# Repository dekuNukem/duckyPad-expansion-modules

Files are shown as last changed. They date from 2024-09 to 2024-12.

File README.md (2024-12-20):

# duckyPad Expansion Module

[Pre-order](https://www.kickstarter.com/projects/dekunukem/duckypad-pro-advanced-macro-scripting-beyond-qmk-via) | [Official Discord](https://discord.gg/4sJCBx5) | [Project Page](https://github.com/dekuNukem/duckyPad-Pro) | [Table of Contents](#table-of-contents)

duckyPad Expansion Module lets you wire up external **switches / buttons / foot pedals** to your duckyPad Pro.

* **8 Channels** Per Module

* **Daisy-Chain** up to 32 Channels

* USB-C Connector

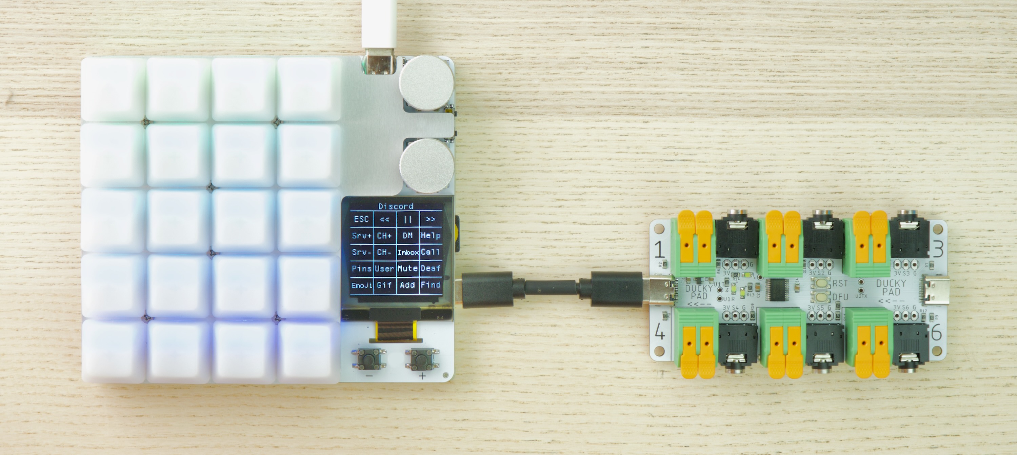
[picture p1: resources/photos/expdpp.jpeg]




## Table of Contents

- [Kit Assembly](#kit-assembly)
- [Connection Overview](#connection-overview)
	- [Terminal Block](#connection-terminal-block)
	- [3.5mm Audio Jack](#connection-35mm-audio-jack)
	- [Pin Headers](#connection-pin-headers)
- [Key Test](#key-test)
- [Configurator](#configurator)

## Kit Assembly

* **Wash your hands first** to discharge static electricity

You should have the following parts:

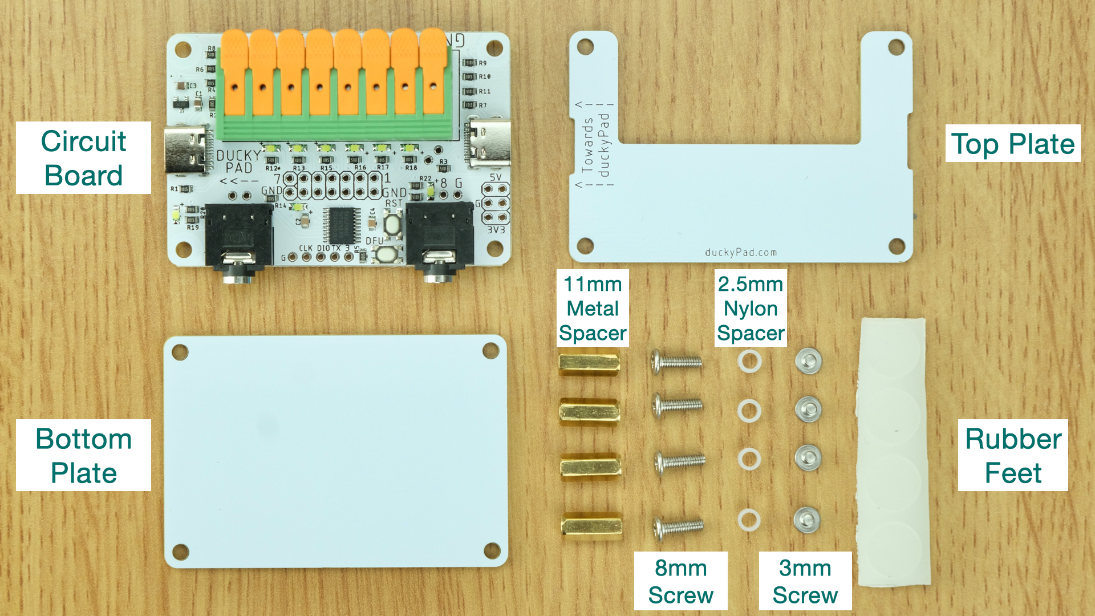
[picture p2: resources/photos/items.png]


Insert the `8mm Screws` in `Bottom Plate`:

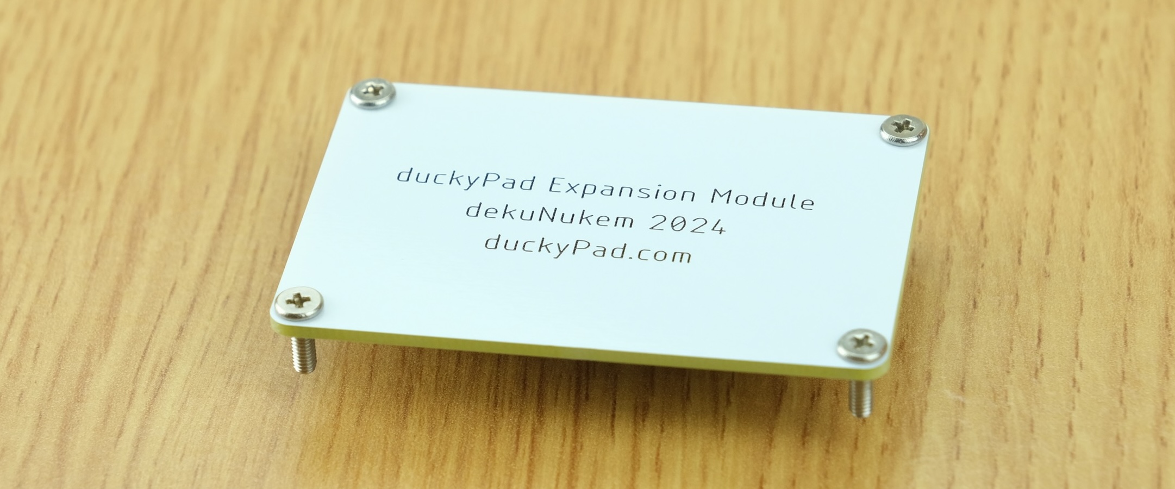
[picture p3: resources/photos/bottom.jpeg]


Place **something rigid** against the back, and flip over.

The screws should stay in place.

Put on **2.5mm Nylon Spacers**.

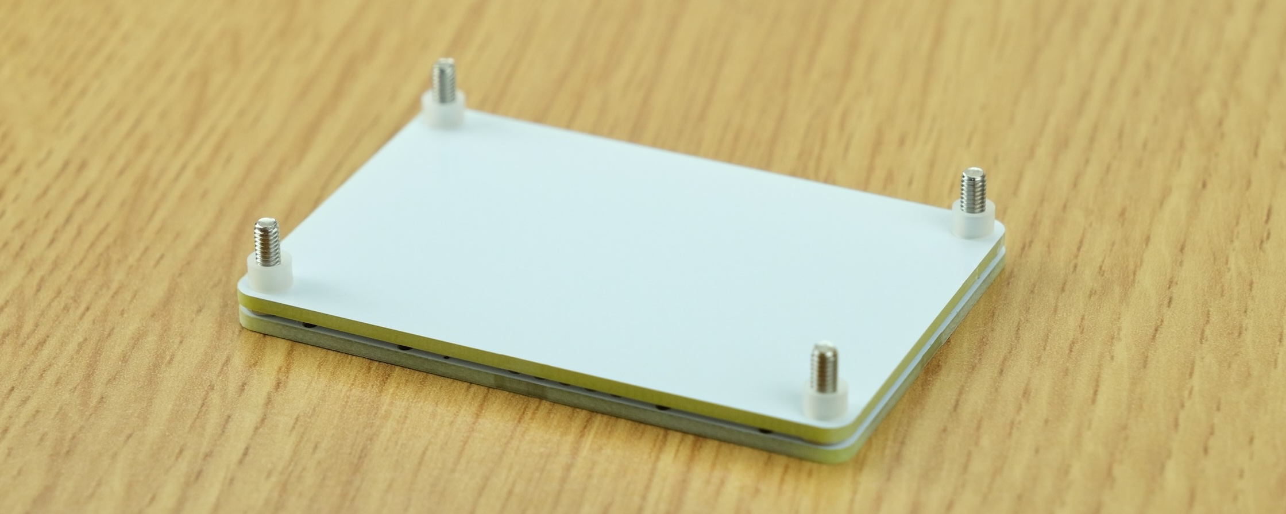
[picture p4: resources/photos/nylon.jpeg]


Insert the `Circuit Board`.

Then the `8mm Metal Spacer`

* **Moderately tighten** with a socket bit if available

* Avoid scratching the PCB or nearby components.

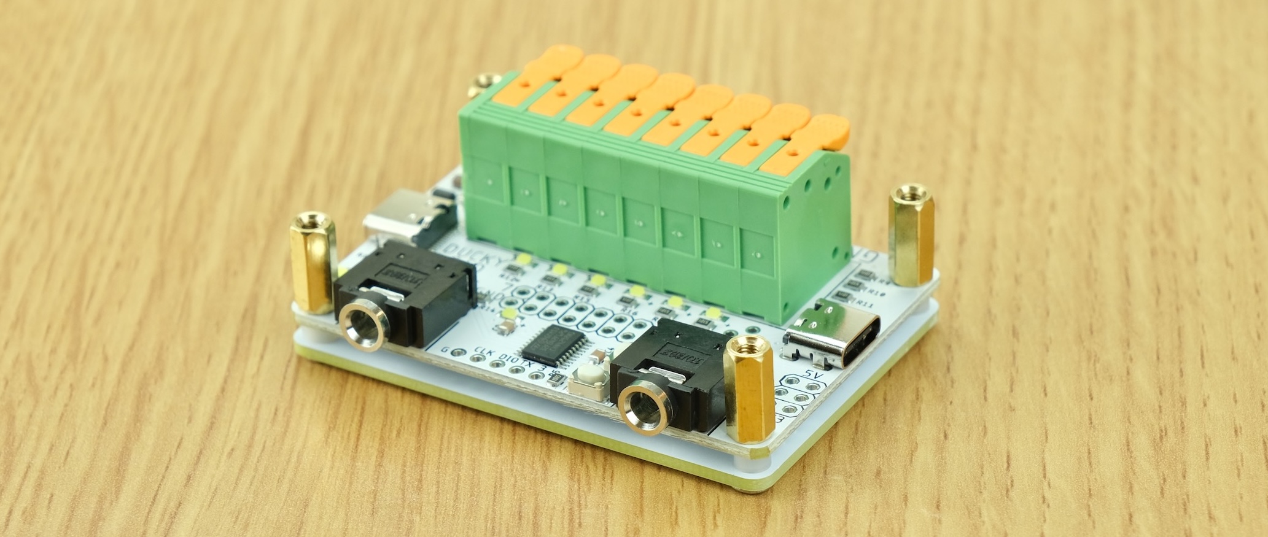
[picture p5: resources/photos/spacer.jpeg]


Leave the `Top Plate` off for now.

You can install it after everything is wired up.

## Back to duckyPad!

If you're just starting, **set up your duckyPad first by [following the User Guide](https://dekunukem.github.io/duckyPad-Pro/doc/getting_started.html)**

Play with scripts on built-in switches and encoders, continue here once familiarised.

## Connection Overview

**8 Channels** are available per module.

* Numbered 1 to 8
* A channel is **considered active** when it is **shorted to ground (GND)**.

Therefore, to wire up a switch, you just need to:

* Connect **one side** to **GND**
* And the **other side** to the **desired channel**

---------

You can make connections via:

* Terminal Block
* 3.5mm Jack
* Pin Headers

## Connection: Terminal Block

Take a look at the `terminal block`:

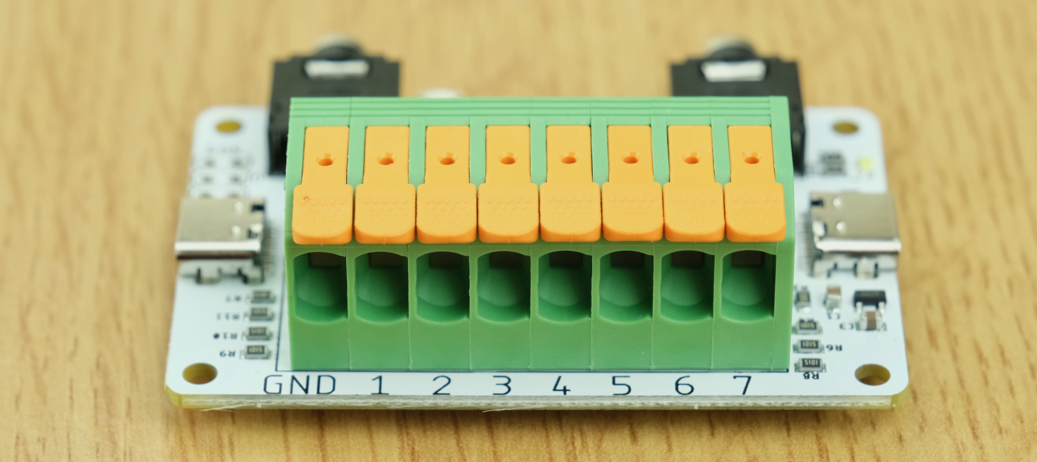
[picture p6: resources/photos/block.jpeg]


Contains **Channel 1 to 7** and **GND**

To wire up a switch, connect it between a channel and GND.

-------

As an example, here's a simple button with two wires:

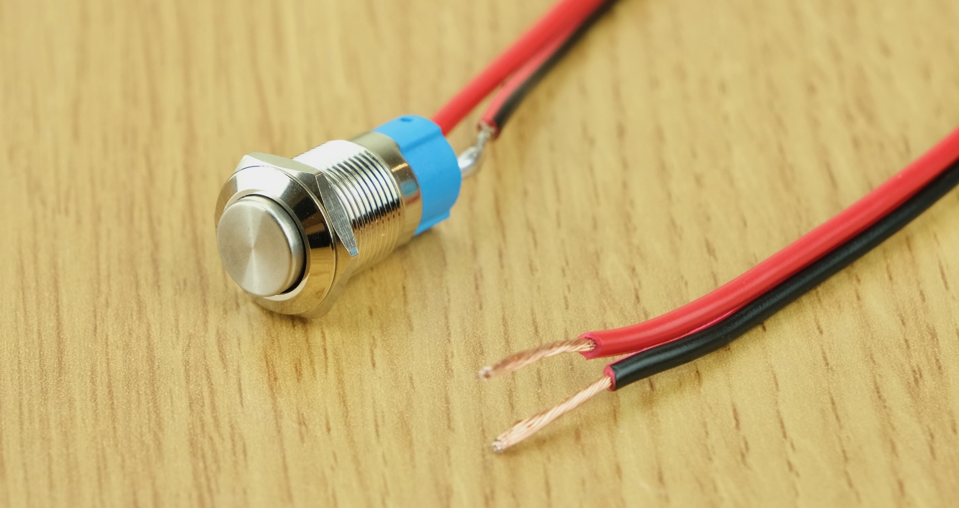
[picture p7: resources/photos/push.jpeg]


* When not pushed, the wires are isolated.
* When pushed, they are **connected together**.

Therefore, we just need to attach one wire to GND, and the other to a channel.

* Flip up the lever for GND and the desired channel

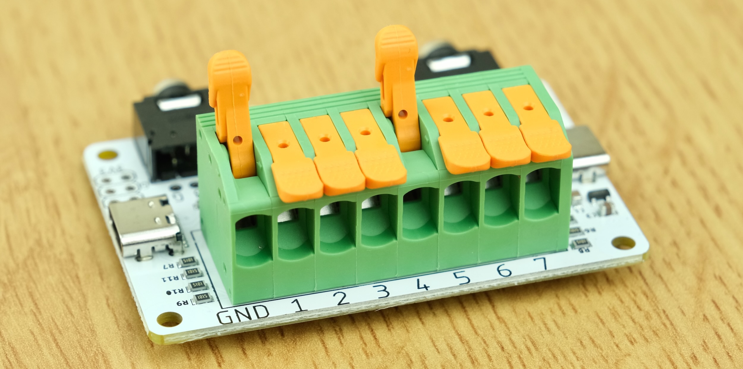
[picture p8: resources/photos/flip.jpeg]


* Strip around half inch / 1.2cm of conductor
* Insert into the hole
* Flip lever back down

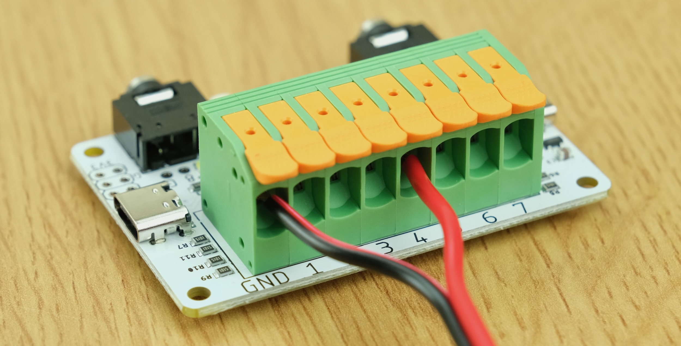
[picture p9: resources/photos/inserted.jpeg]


## Connection: 3.5mm Audio Jack

Two 3.5mm TRS (Tip, Ring, Sleeve) connectors are available.

Sleeve is connected to GND.

Tip and Ring are connected to channels shown below.

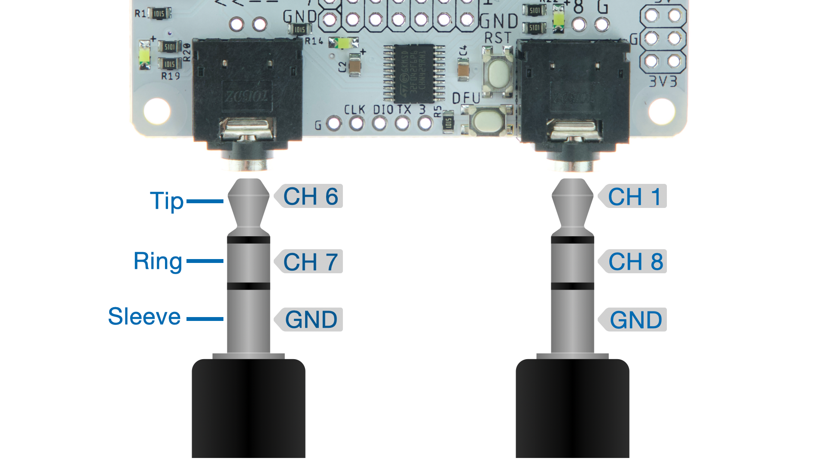
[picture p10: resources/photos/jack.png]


## Connection: Pin Headers

All channels are also available on pin headers.

You can install a header or solder wires directly to them.

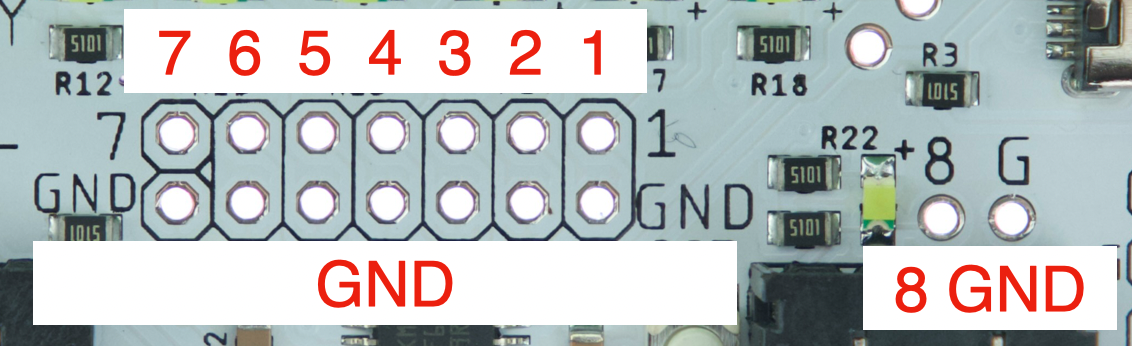
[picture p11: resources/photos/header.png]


## Key Test

Use a USB-C cable and connect the module as shown.

* Make sure the `Towards duckyPad` marking faces duckyPad

* The other end is used for daisy-chaining

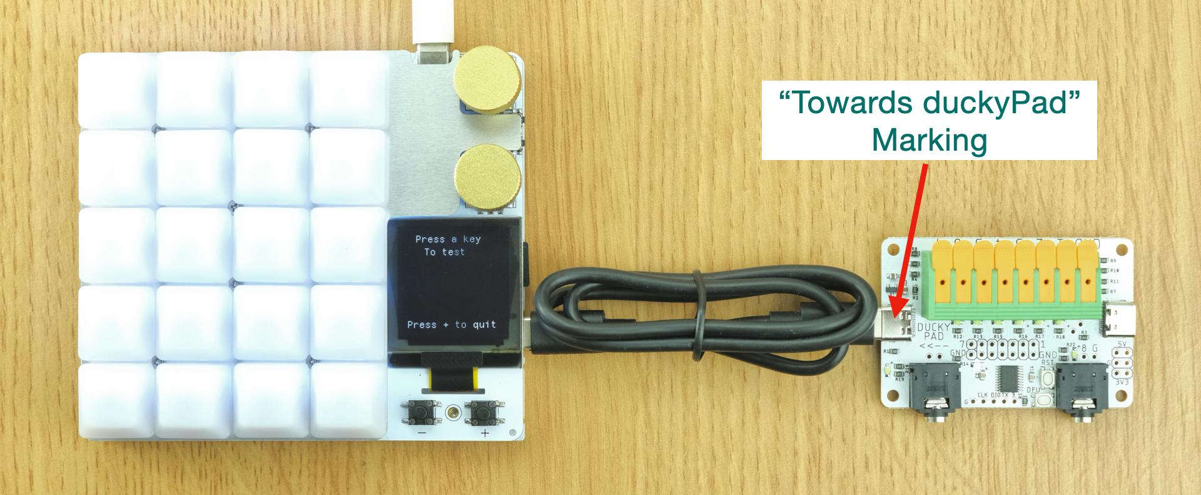
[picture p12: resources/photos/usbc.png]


Press the `Key Test` script in `Welcome` profile

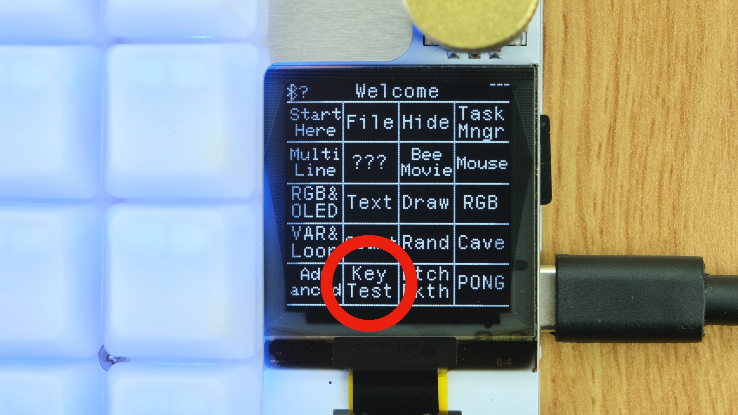
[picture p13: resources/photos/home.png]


Press a built-in switch, the screen should respond.

Then activate a channel on the expansion module.

The corresponding LED should light up:

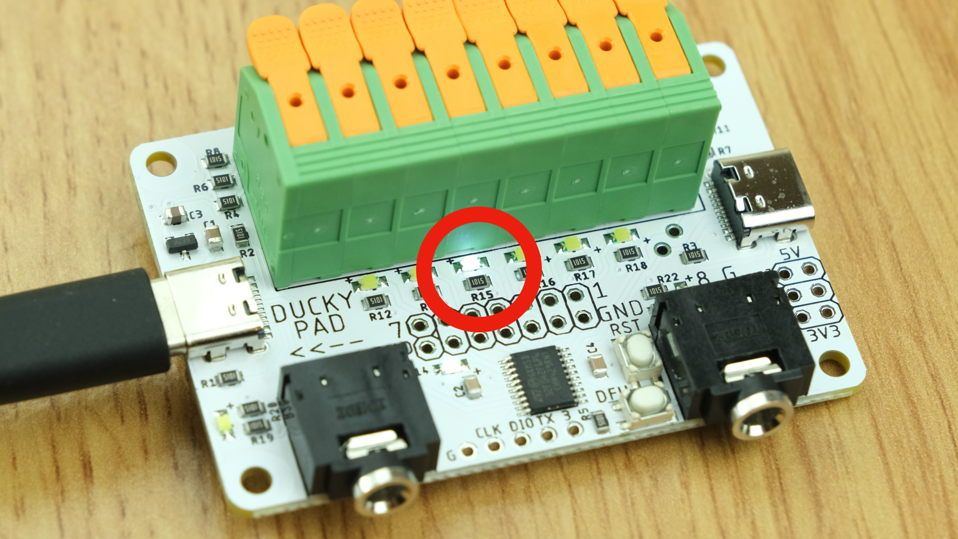
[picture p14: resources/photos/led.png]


The screen should show too:

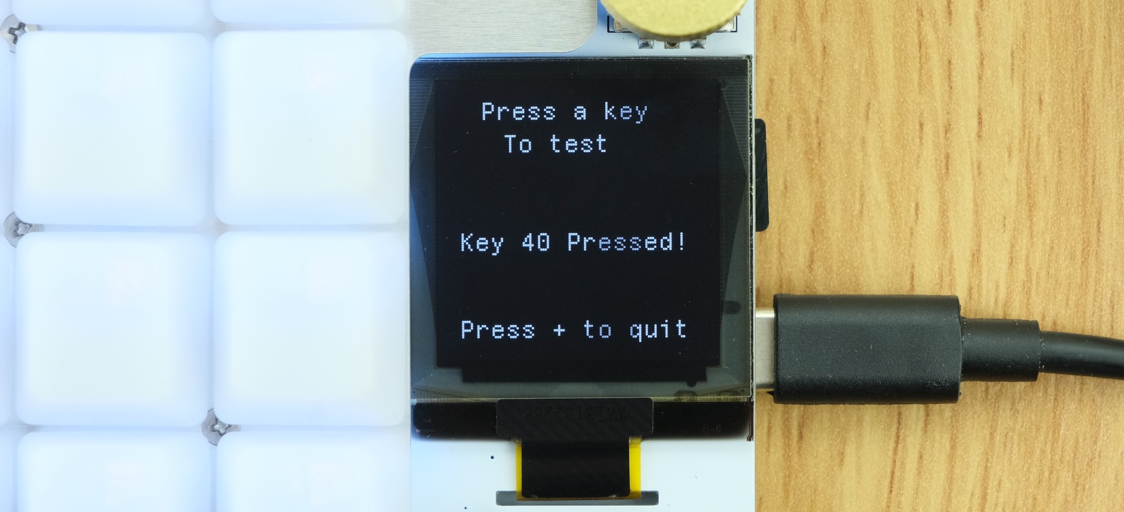
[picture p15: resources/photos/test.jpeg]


If so, congrats! Your wiring is correct.

## Configurator

You can assign actions to expansion channels just like any other key.

Module 1 is closest to duckyPad, up to 4 can be daisy-chained.

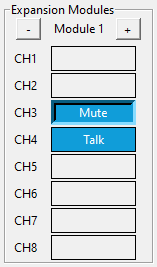
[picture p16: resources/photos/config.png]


Some notes:

* If using a flip switch, select `Disable Auto-Repeat`.
* So the script doesn't repeat after changing state.

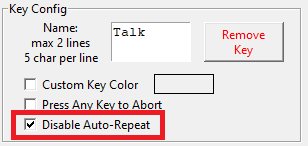
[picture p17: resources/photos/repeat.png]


* Each channel can have different scripts for `onPress` and `onRelease`.
	* `onPress` is when a channel goes from inactive to active
	* `onRelase` is the opposite



## Questions or Comments?

Please feel free to [open an issue](https://github.com/dekuNukem/duckypad-pro/issues), ask in the [official duckyPad discord](https://discord.gg/4sJCBx5), or email `dekuNukem`@`gmail`.`com`!

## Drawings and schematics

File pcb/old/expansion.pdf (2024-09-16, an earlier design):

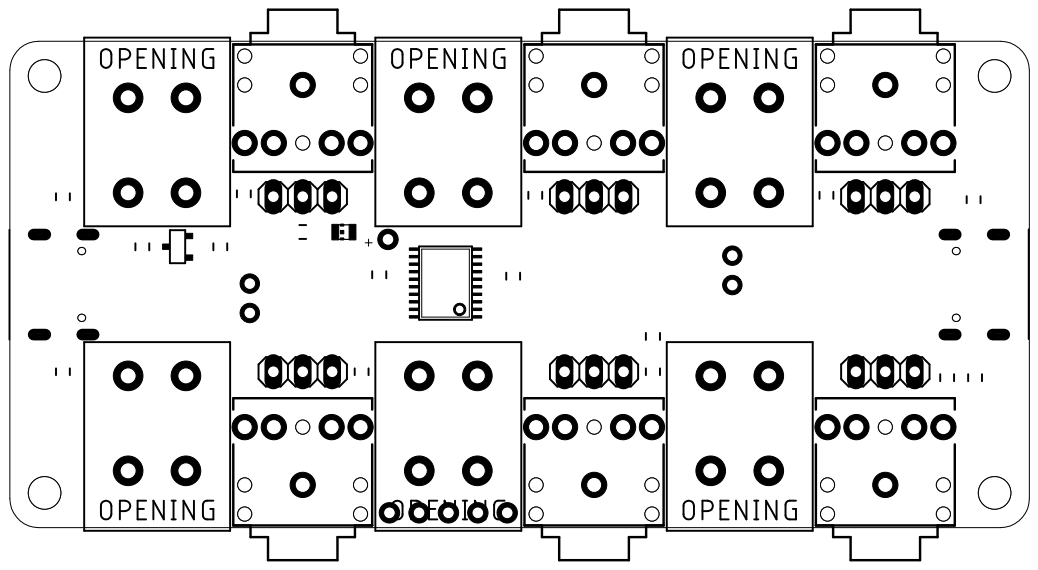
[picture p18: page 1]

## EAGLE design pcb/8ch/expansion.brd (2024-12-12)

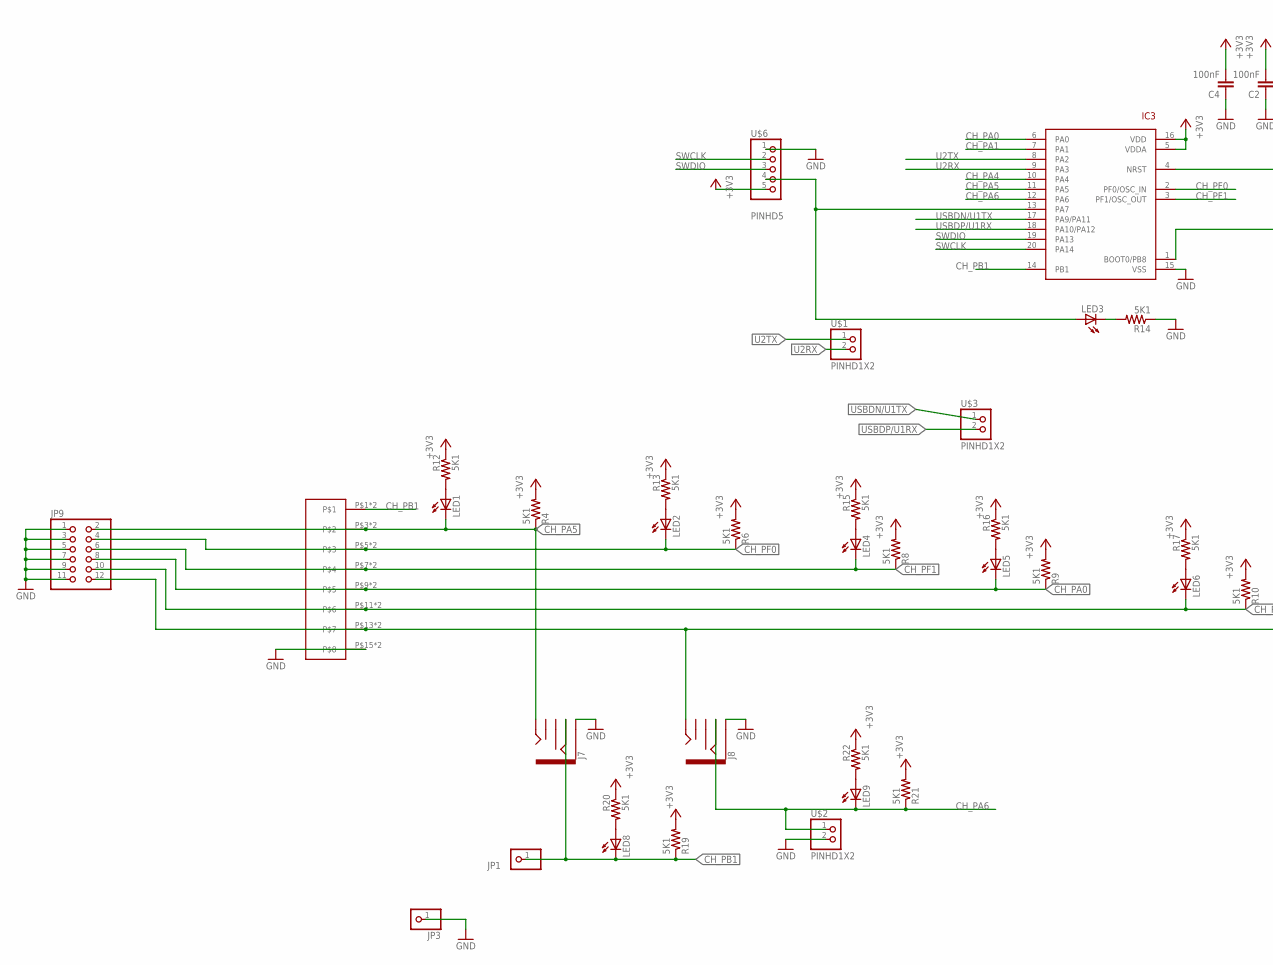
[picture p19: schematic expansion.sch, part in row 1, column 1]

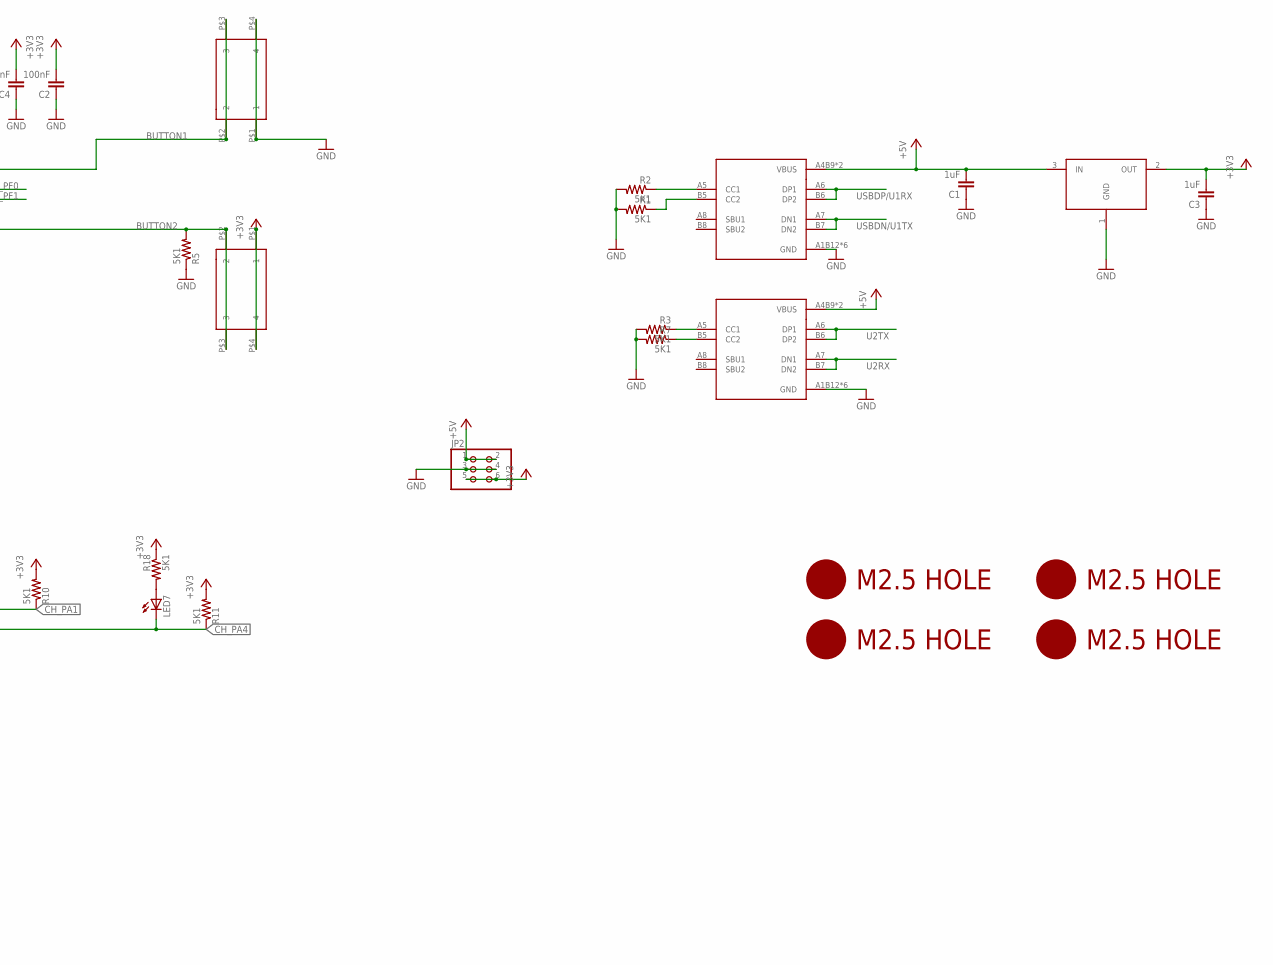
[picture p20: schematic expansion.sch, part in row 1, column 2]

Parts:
C1, C3: 1uF; 0805
C2, C4: 100nF; 0805
IC3: STM32F042F4; TSSOP20
J7, J8: AUDIO_JACK_3.5MM_PTH; AUDIO-JACK
JP1, JP3: PINHD-1X1; 1X01
JP2: PINHD-2X3; 2X03
JP9: PINHD-2X6; 2X06
LED1, LED2, LED3, LED4, LED5, LED6, LED7, LED8, LED9: LEDCHIP-LED0805; CHIP-LED0805
R1, R2, R3, R4, R5, R6, R7, R8, R9, R10, R11, R12, R13, R14, R15, R16, R17, R18, R19, R20, R21, R22: 5K1; 0805
SW3, SW4: 324_SW; 342_SWICH_FOOT
U1, U2: USBC_16P; USBC_16P_FOOT
U4: XC6206_DEV; SOT23R_INFINEON
U$1, U$2, U$3: PINHD1X2; 1X02
U$6: PINHD5; 1X05
U$8, U$9, U$10, U$11: M2.5HOLE
U$14: DG2204R-5.0-8DG2204-8; DG2204R-8

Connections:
+3V3: C2.2, C3.2, C4.2, IC3.5 (VDDA), IC3.16 (VDD), JP2.5, JP2.6, R4.2, R6.2, R8.2, R9.2, R10.2, R11.2, R12.1, R13.1, R15.1, R16.1, R17.1, R18.1, R19.2, R20.1, R21.2, R22.1, SW4.P$1 (1), SW4.P$4 (4), U4.2 (OUT), U$6.5
+5V: C1.2, JP2.1, JP2.2, U1.A4B9 (VBUS), U1.B4A9 (VBUS), U2.A4B9 (VBUS), U2.B4A9 (VBUS), U4.3 (IN)
BUTTON1: IC3.4 (NRST), SW3.P$2 (2), SW3.P$3 (3)
BUTTON2: IC3.1 (BOOT0/PB8), R5.2, SW4.P$2 (2), SW4.P$3 (3)
CH_PA0: IC3.6 (PA0), JP9.8, LED5.C, R9.1, U$14.P$9, U$14.P$10
CH_PA1: IC3.7 (PA1), JP9.10, LED6.C, R10.1, U$14.P$11, U$14.P$12
CH_PA4: IC3.10 (PA4), J8.TIP, JP9.12, LED7.C, R11.1, U$14.P$13, U$14.P$14
CH_PA5: IC3.11 (PA5), J7.TIP, JP9.2, LED1.C, R4.1, U$14.P$3, U$14.P$4
CH_PA6: IC3.12 (PA6), J8.RING, LED9.C, R21.1, U$2.1
CH_PB1: IC3.14 (PB1), J7.RING, JP1.1, LED8.C, R19.1, U$14.P$1, U$14.P$2
CH_PF0: IC3.2 (PF0/OSC_IN), JP9.4, LED2.C, R6.1, U$14.P$5, U$14.P$6
CH_PF1: IC3.3 (PF1/OSC_OUT), JP9.6, LED4.C, R8.1, U$14.P$7, U$14.P$8
GND: C1.1, C2.1, C3.1, C4.1, IC3.15 (VSS), J7.SLEEVE, J8.SLEEVE, JP2.3, JP2.4, JP3.1, JP9.1, JP9.3, JP9.5, JP9.7, JP9.9, JP9.11, R1.2, R2.2, R3.2, R5.1, R7.2, R14.1, SW3.P$1 (1), SW3.P$4 (4), U1.A1B12 (GND), U1.B11A12 (GND), U1.P$13 (GND), U1.P$14 (GND), U1.P$15 (GND), U1.P$16 (GND), U2.A1B12 (GND), U2.B11A12 (GND), U2.P$13 (GND), U2.P$14 (GND), U2.P$15 (GND), U2.P$16 (GND), U4.1 (GND), U$2.2, U$6.1, U$14.P$15, U$14.P$16
unnamed: R3.1, U1.A5 (CC1)
unnamed: R7.1, U1.B5 (CC2)
unnamed: LED1.A, R12.2
unnamed: LED2.A, R13.2
unnamed: LED4.A, R15.2
unnamed: LED5.A, R16.2
unnamed: LED6.A, R17.2
unnamed: LED7.A, R18.2
unnamed: LED8.A, R20.2
unnamed: IC3.13 (PA7), LED3.A, U$6.4
unnamed: LED3.C, R14.2
unnamed: LED9.A, R22.2
unnamed: R1.1, U2.B5 (CC2)
unnamed: R2.1, U2.A5 (CC1)
SWCLK: IC3.20 (PA14), U$6.2
SWDIO: IC3.19 (PA13), U$6.3
U2RX: IC3.9 (PA3), U1.A7 (DN1), U1.B7 (DN2), U$1.2
U2TX: IC3.8 (PA2), U1.A6 (DP1), U1.B6 (DP2), U$1.1
USBDN/U1TX: IC3.17 (PA9/PA11), U2.A7 (DN1), U2.B7 (DN2), U$3.1
USBDP/U1RX: IC3.18 (PA10/PA12), U2.A6 (DP1), U2.B6 (DP2), U$3.2

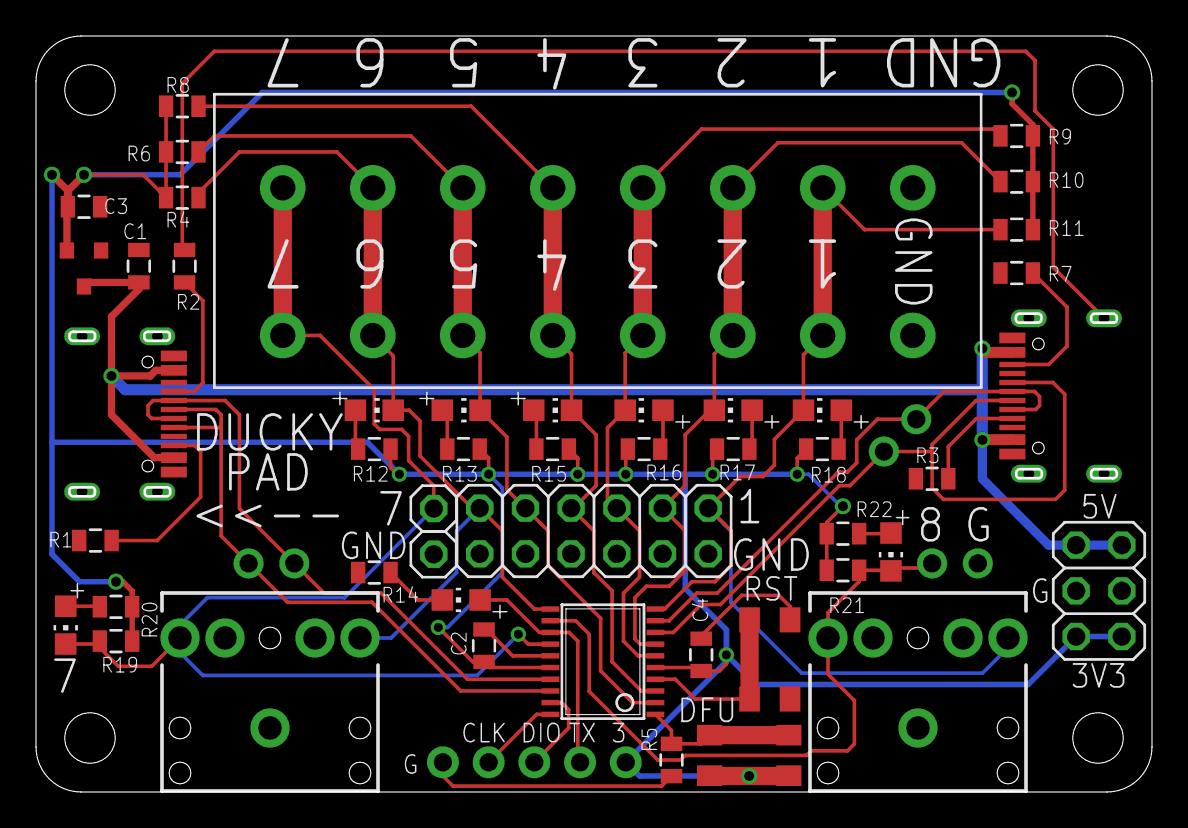
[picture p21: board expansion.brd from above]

Board: 2 copper layers, 62.0 x 42.0 mm, 56 parts (0 on the bottom side), 33 nets.

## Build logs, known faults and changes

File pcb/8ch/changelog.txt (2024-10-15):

2024 10 15

Added LED on PB1 channel

moved TX pin from PA6 to PA7

PA6 now is an additional channel

PA6 on sleeve

added LEDs on PA6

hooked up LED to TX pin, dual purpose.

Ch	Pin
1	PA4
2	PA1
3	PA0
4	PF1
5	PF0
6	PA5
7	PB1
8	PA6

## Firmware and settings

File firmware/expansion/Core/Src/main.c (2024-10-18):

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
/* Includes ------------------------------------------------------------------*/
#include "main.h"

/* USER CODE BEGIN Includes */
#include <stdio.h>
#include <string.h>
#include <stdlib.h>
#include <time.h>
#include "buttons.h"
#include "cQueue.h"
#include "softserial.h"
#include "delay_us.h"

/* USER CODE END Includes */

/* USER CODE BEGIN PTD */
int stdin_getchar (void)
{
  return 0;
}

int stdout_putchar (int ch) {
  return 0;
}
void ttywrch (int ch) {
  return;
}
/* USER CODE END PTD */

/* USER CODE BEGIN PD */

/*
2024 08 12
0.0.1
first commit

2024 10 15
0.1.0
8 channels
LED double blinks with button press and upstream receive
*/
uint8_t fw_version_major = 0;
uint8_t fw_version_minor = 1;
uint8_t fw_version_patch = 0;

#define UART_BUF_SIZE 16

uint8_t towards_duckypad_tx_buf[UART_BUF_SIZE];
uint8_t towards_duckypad_rx_buf[UART_BUF_SIZE];
uint8_t away_from_duckypad_tx_buf[UART_BUF_SIZE];
uint8_t away_from_duckypad_rx_buf[UART_BUF_SIZE];

uint8_t starting_id;

volatile uint8_t current_state;

/* USER CODE END PD */

/* USER CODE BEGIN PM */
#define LED_ON() HAL_GPIO_WritePin(SSTX_USERLED_GPIO_Port, SSTX_USERLED_Pin, GPIO_PIN_SET)
#define LED_OFF() HAL_GPIO_WritePin(SSTX_USERLED_GPIO_Port, SSTX_USERLED_Pin, GPIO_PIN_RESET)
#define STATE_UNINITIALIZED 0
#define STATE_READY 1
/* USER CODE END PM */

TIM_HandleTypeDef htim2;
TIM_HandleTypeDef htim16;

UART_HandleTypeDef huart1;
UART_HandleTypeDef huart2;

/* USER CODE BEGIN PV */

#define towards_duckypad_uart (huart1)
#define away_from_duckypad_uart (huart2)

int fputc(int ch, FILE *f)
{
  // __disable_irq();
  // softserial_putc(ch);
  // __enable_irq();
  return ch;
}

void towards_duckypad_send(uint8_t data)
{
  HAL_UART_Transmit(&towards_duckypad_uart, &data, 1, 100);
  // printf("TDS:%02x\n", data);
}

void away_from_duckypad_send(uint8_t data)
{
  HAL_UART_Transmit(&away_from_duckypad_uart, &data, 1, 100);
  // printf("AFDS:%02x\n", data);
}

/* USER CODE END PV */

void SystemClock_Config(void);
static void MX_GPIO_Init(void);
static void MX_USART2_UART_Init(void);
static void MX_TIM2_Init(void);
static void MX_TIM16_Init(void);
static void MX_USART1_UART_Init(void);
/* USER CODE BEGIN 0 */

volatile uint32_t global_frame;
volatile uint32_t animation_start_frame;

void animation_handler(void)
{
  if(current_state != STATE_READY)
    return;
  global_frame++;
  uint32_t current_frame = global_frame - animation_start_frame;
  if(current_frame <= 2)
    LED_OFF();
  else if(current_frame <= 4)
    LED_ON();
  else if(current_frame <= 6)
    LED_OFF();
  else
    LED_ON();
}

// happens every 25ms
void HAL_TIM_PeriodElapsedCallback(TIM_HandleTypeDef *htim)
{
  animation_handler();
  channel_update(starting_id);
}

void double_blink(void)
{
  animation_start_frame = global_frame;
}

uint32_t get_rand_delay_ms(void)
{
  srand(micros());
  return 50 + (rand() % 16) * 10;
}

#define TOP_TWO_BITS 0xc0
#define CMD_ASK_START_ID_BITMASK 0x0
#define CMD_ASSIGN_START_ID_BITMASK 0x40

void towards_duckypad_receive_parse(uint8_t this_cmd)
{
  // printf("TDR:%02x\n", this_cmd);
  if(this_cmd & CMD_ASSIGN_START_ID_BITMASK)
  {
    starting_id = towards_duckypad_rx_buf[0] & 0x3f;
    current_state = STATE_READY;
    LED_ON();
    // printf("Got ID: %x\n", starting_id);
  }
}

void away_from_duckypad_receive_parse(uint8_t this_cmd)
{
  // printf("AFDR:%02x\n", this_cmd);
  uint8_t cmd_type = this_cmd & TOP_TWO_BITS;
  if(cmd_type == CMD_ASK_START_ID_BITMASK)
  {
    if(this_cmd & 0x7 != fw_version_major)
      return;
    if(current_state == STATE_UNINITIALIZED)
      return;
    uint8_t next_start_id = starting_id + CHANNEL_COUNT;
    if(next_start_id >= MAX_CHANNELS)
      return;
    away_from_duckypad_send(next_start_id | CMD_ASSIGN_START_ID_BITMASK);
  }
  else if(cmd_type == CMD_SW_PRESS_BITMASK || cmd_type == CMD_SW_RELEASE_BITMASK)
  {
    q_push(&switch_event_queue, &this_cmd);
  }
}

void HAL_UART_RxCpltCallback(UART_HandleTypeDef *huart)
{
  if(huart == &towards_duckypad_uart)
    towards_duckypad_receive_parse(towards_duckypad_rx_buf[0]);
  else
    away_from_duckypad_receive_parse(away_from_duckypad_rx_buf[0]);
}

#define UART_QUEUE_SEND_FREQ_MS 10

/* USER CODE END 0 */

/**
  * @brief  The application entry point.
  * @retval int
  */
int main(void)
{
  /* MCU Configuration--------------------------------------------------------*/

  /* Reset of all peripherals, Initializes the Flash interface and the Systick. */
  HAL_Init();

  /* Configure the system clock */
  SystemClock_Config();

  /* Initialize all configured peripherals */
  MX_GPIO_Init();
  MX_USART2_UART_Init();
  MX_TIM2_Init();
  MX_TIM16_Init();
  MX_USART1_UART_Init();
  /* USER CODE BEGIN 2 */
  delay_us_init(&htim2);
  // softserial_init(SOFTSERIAL_TX_GPIO_Port, SOFTSERIAL_TX_Pin);
  sw_event_queue_init();
  HAL_TIM_Base_Start_IT(&htim16);
  current_state = STATE_UNINITIALIZED;
  /* USER CODE END 2 */

  /* Infinite loop */
  /* USER CODE BEGIN WHILE */
  printf("duckyPad Pro Expansion Module v%d.%d.%d\n", fw_version_major, fw_version_minor, fw_version_patch);
  while (1)
  {
    HAL_UART_Receive_IT(&towards_duckypad_uart, towards_duckypad_rx_buf, 1);
    HAL_UART_Receive_IT(&away_from_duckypad_uart, away_from_duckypad_rx_buf, 1);
    /* USER CODE END WHILE */

    /* USER CODE BEGIN 3 */

    if(current_state == STATE_UNINITIALIZED)
    {
      HAL_Delay(get_rand_delay_ms());
      uint8_t cmd_ask_starting_id_towards_duckypad = fw_version_major & 0x3f;
      towards_duckypad_send(cmd_ask_starting_id_towards_duckypad);
      HAL_GPIO_TogglePin(SSTX_USERLED_GPIO_Port, SSTX_USERLED_Pin);
    }
    else
    {
      HAL_Delay(UART_QUEUE_SEND_FREQ_MS);
      uint8_t this_cmd;
      if(q_pop(&switch_event_queue, &this_cmd) == 0)
        continue;
      towards_duckypad_send(this_cmd);
      double_blink();
    }
  }
  /* USER CODE END 3 */
}

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


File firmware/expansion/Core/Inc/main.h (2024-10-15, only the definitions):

#define USER_BUTTON_Pin GPIO_PIN_8
#define USER_BUTTON_GPIO_Port GPIOB
#define CH5_Pin GPIO_PIN_0
#define CH5_GPIO_Port GPIOF
#define CH4_Pin GPIO_PIN_1
#define CH4_GPIO_Port GPIOF
#define CH3_Pin GPIO_PIN_0
#define CH3_GPIO_Port GPIOA
#define CH2_Pin GPIO_PIN_1
#define CH2_GPIO_Port GPIOA
#define CH1_Pin GPIO_PIN_4
#define CH1_GPIO_Port GPIOA
#define CH6_Pin GPIO_PIN_5
#define CH6_GPIO_Port GPIOA
#define CH8_Pin GPIO_PIN_6
#define CH8_GPIO_Port GPIOA
#define SSTX_USERLED_Pin GPIO_PIN_7
#define SSTX_USERLED_GPIO_Port GPIOA
#define CH7_Pin GPIO_PIN_1
#define CH7_GPIO_Port GPIOB

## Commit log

2024-08-24 commented out some printf
2024-10-09 working on new PCB
    [expansion.brd, expansion.sch]
2024-10-09 finishing touch
    [expansion.brd, expansion.sch]
2024-10-15 added PB1 LED
    [expansion.brd, expansion.sch]
2024-10-15 added 2 aux channels, cleanup
    [expansion.brd, expansion.sch]
2024-10-15 moved channel 7 to terminal and on header
    [expansion.brd, expansion.sch]
2024-10-15 silkscreen cleanup
    [expansion.brd]
2024-10-18 finishing touches
    [expansion.brd]
2024-11-04 making cover plates
    [top.brd, top.sch]
2024-11-04 added plate gerber
2024-12-12 adjusted silkscreen
    [expansion.brd]
2024-12-12 added more detailed instruction about audio jack and pin headers

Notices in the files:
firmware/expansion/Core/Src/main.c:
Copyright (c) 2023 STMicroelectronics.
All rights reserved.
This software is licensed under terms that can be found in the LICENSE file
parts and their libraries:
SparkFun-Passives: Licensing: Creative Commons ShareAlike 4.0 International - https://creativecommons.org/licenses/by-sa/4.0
